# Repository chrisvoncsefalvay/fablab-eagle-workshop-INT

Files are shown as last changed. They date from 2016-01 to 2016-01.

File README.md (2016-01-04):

# FabLab EAGLE workshop (INTRODUCTORY)
The official repo for the Munich Fablab EAGLE introductory course 

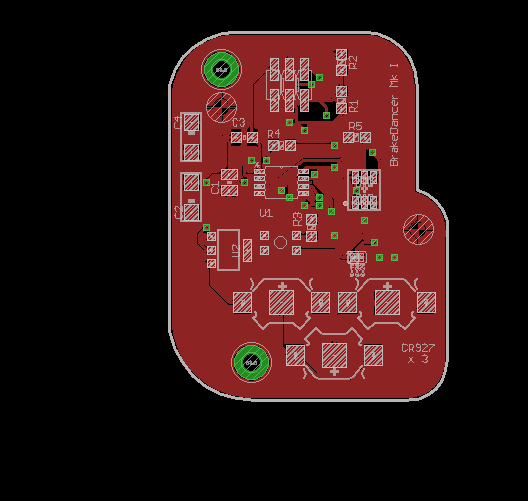
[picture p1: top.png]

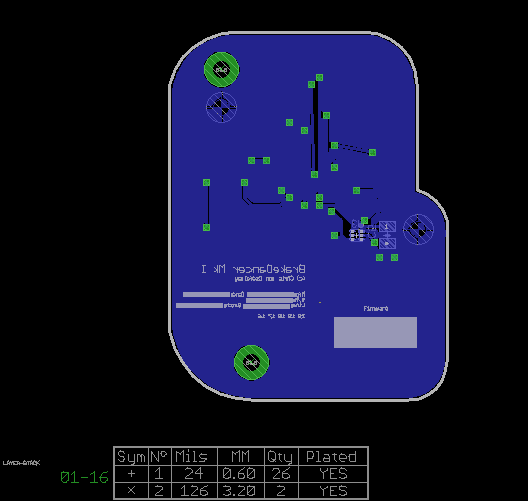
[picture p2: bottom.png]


## The board
The board used to demonstrate EAGLE's functionality is a small ATtiny based brake light tester. The general idea is as follows. Upon resetting the device, an ambient light measurement is taken for five seconds. At the end of the five seconds, you must have attached the device to your light. The device then enters measurement mode. The LED will light up red and turn green if and only if the brake light has lit up. After 60 seconds of no signal, the device will enter sleep. 

### Specs
The device must accommodate the ATtiny, an I2C based light sensor, a battery, a tricolour LED, a power management circuit and all else that's needed for the board's functioning.

The board is driven by three 3V CR927 batteries in series, yielding 9V. This is converted to 5V by the LDO (U2).

Most of the heavy lifting is done by the MCU. The MCU has to be programmable through ICSP headers, though these will not necessarily be mounted in production devices (potentially replaced by a pogo/bed of nails approach).

### Implementation

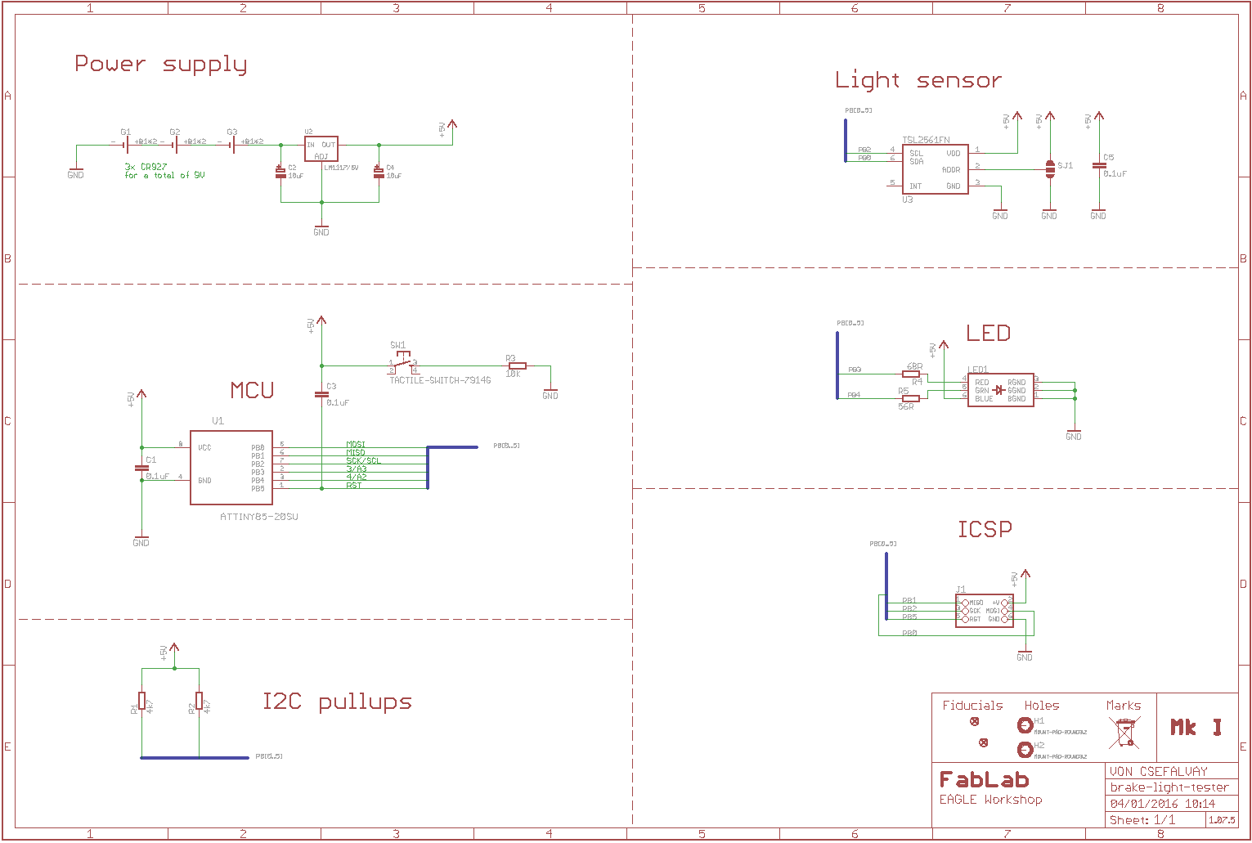
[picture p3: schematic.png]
Schematic


This is a possible implementation, but not the only possible implementation. Be creative, use your mind.

### Board design considerations
The usual considerations apply, but don't forget to
- leave enough space,
- provide fiducials and mount holes,
- use largeish components (1206/1210) and large pads for hand soldering ('W pads') where available,
- stick to two layers, and
- avoid the autorouter.

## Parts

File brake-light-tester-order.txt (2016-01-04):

Order list for /Users/CVoncsefalvay/Developer/fablab-EAGLE-training/brake-light-tester.sch
Exported from EAGLE with DesignLink

Quantity	Value	Package	Order code	Manufacturer	Manuf. Code	Availability	Price (from)	Description
2	0.1uF	C1210	2211074	TDK	CGA5L2C0G1H104J160AA	29910	0.147	TDK - CGA5L2C0G1H104J160AA - CAP, MLCC, C0G/NP0, 100NF, 50V, 1206
2	10uF	EIA6032-28/C-R	197130	AVX	TAJA106K010RNJ	28494	0.0741	AVX - TAJA106K010RNJ - CAP, TANT, 10UF, 10V, CASE A
1	0.1uF	C1206	2211074	TDK	CGA5L2C0G1H104J160AA	29910	0.147	TDK - CGA5L2C0G1H104J160AA - CAP, MLCC, C0G/NP0, 100NF, 50V, 1206
2	FIDUCIALROUND	PASS-ROUND	unknown					
3	10MM_SM_COIN_CELL_CLIP	10MM_SM_COIN_CELL_CLIP	unknown					
2	MOUNT-PAD-ROUND3.2	3,2-PAD	unknown					
1	CON_HEADER_PRG_AVR_ICSP-SMD	M2X3_SMD	unknown					
1		RGBLED_PLCC6	unknown					
2	4k7	R1206	1576638	MULTICOMP	MCHP06W2F4701T5E	43822	0.0145	MULTICOMP - MCHP06W2F4701T5E - RES, THICK FILM, 4K7, 1%, 0.5W, 1206
1	10k	R1206	1469970	VISHAY DRALORIC	CRCW120610K0FKEA	48858	0.0035	VISHAY DRALORIC - CRCW120610K0FKEA - RES, THICK FILM, 10K, 1%, 0.25W, 1206
1	68R	R1206	8067635	YAGEO (PHYCOMP)	RL1206FR-7W0R68L	3000	0.0534	YAGEO (PHYCOMP) - RL1206FR-7W0R68L - RES, THICK FILM, 0R68, 1%, 0.5W, 1206
1	56R	R1206	2057808	PANASONIC ELECTRONIC COMPONENTS	ERJ8GEYJ560V	56569	0.0036	PANASONIC ELECTRONIC COMPONENTS - ERJ8GEYJ560V - RES, THICK FILM, 56R, 5%, 0.25W, 1206
1		SJ_3_PASTE1&2	unknown					
1	TACTILE-SWITCH-7914G	7914G	unknown					
1	ATTINY85-20SU	SOIC127P798X216-8N	1455164	ATMEL	ATTINY85-20SU	4499	0.471	ATMEL - ATTINY85-20SU - MCU, 8BIT, ATTINY, 20MHZ, SOIC-8
1	LM1117/5V	SOT223-R	unknown					
1	TSL2561FN	FN-6	unknown

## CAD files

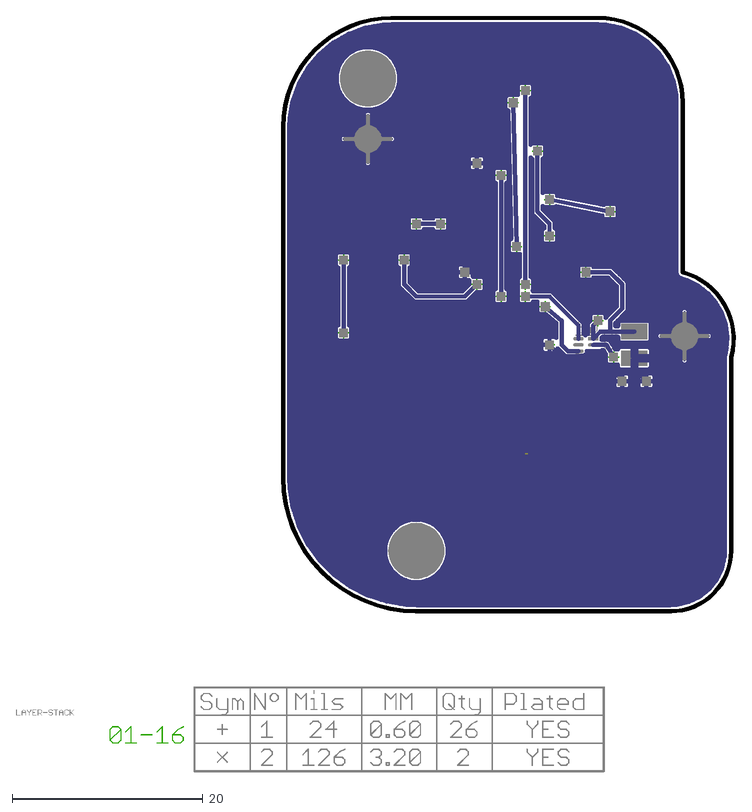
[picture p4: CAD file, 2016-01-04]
brake-light-tester.dxf
75.4 x 79.3

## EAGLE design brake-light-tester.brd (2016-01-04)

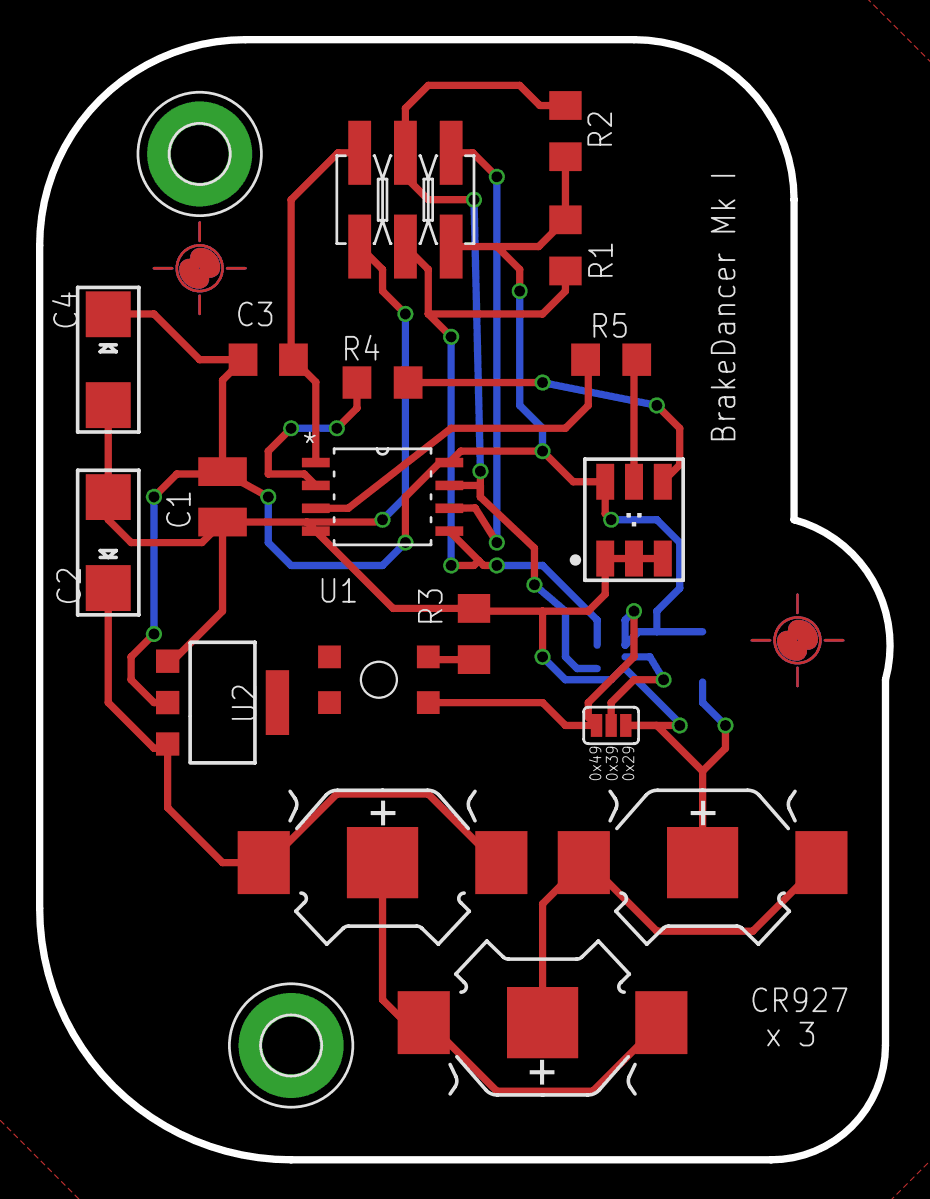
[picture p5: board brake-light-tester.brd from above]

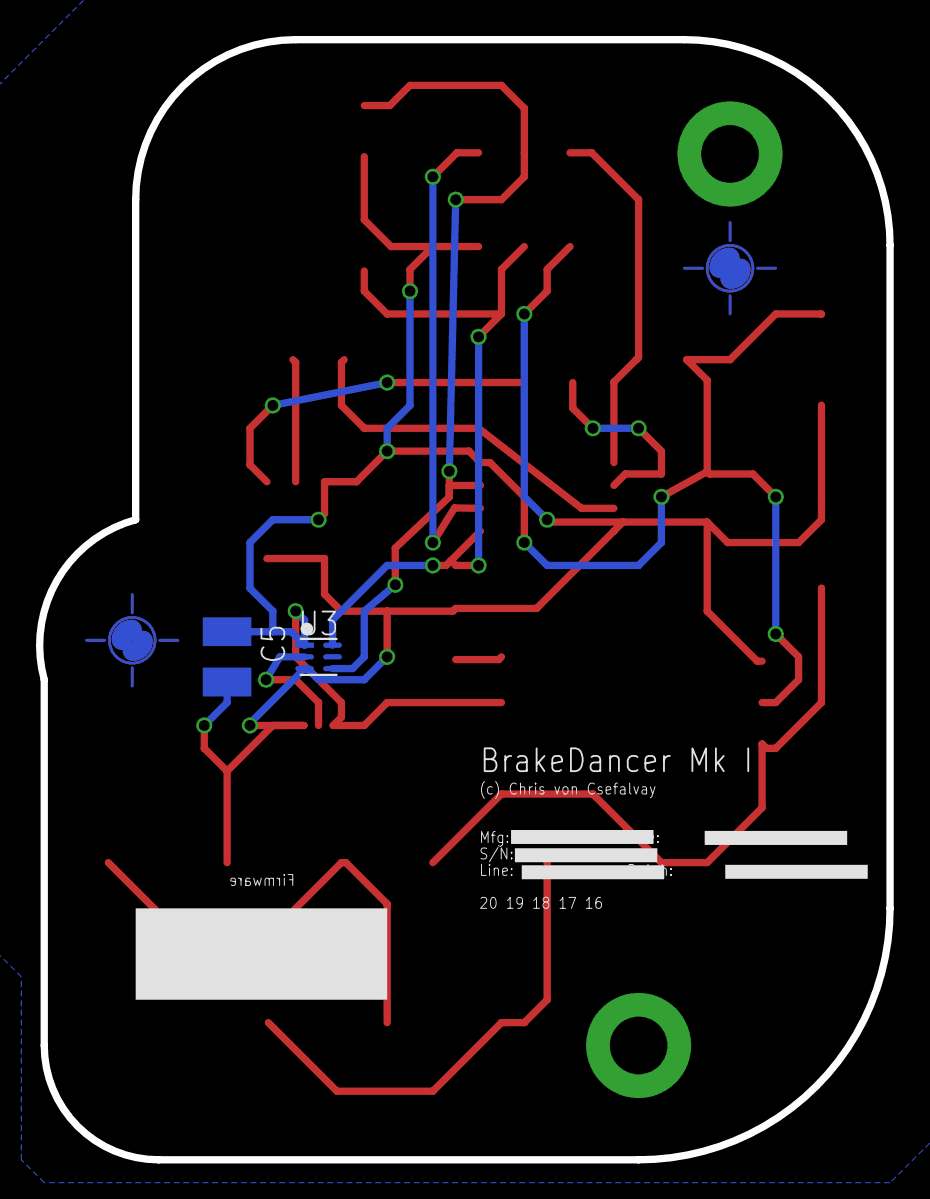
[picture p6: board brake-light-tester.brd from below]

Board: 2 copper layers, 47.2 x 62.2 mm, 25 parts (2 on the bottom side), 15 nets.

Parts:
C1, C5: 0.1uF; C1210
C2, C4: 10uF; EIA6032-28/C-R
C3: 0.1uF; C1206
DRILEGEND: DRILEGEND
FID1, FID2: FIDUCIALROUND; PASS-ROUND
G1, G2, G3: 10MM_SM_COIN_CELL_CLIP
H1, H2: MOUNT-PAD-ROUND3.2; 3,2-PAD
J1: CON_HEADER_PRG_AVR_ICSP-SMD; M2X3_SMD
LED1: RGBLED_PLCC6
R1, R2: 4k7; R1206
R3: 10k; R1206
R4: 68R; R1206
R5: 56R; R1206
SJ1: SJ_3_PASTE1&2
SW1: TACTILE-SWITCH-7914G; 7914G
U1: ATTINY85-20SU; SOIC127P798X216-8N
U2: LM1117/5V; SOT223-R
U3: TSL2561FN; FN-6

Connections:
+5V: C1.1, C3.1, C4.+, C5.1, J1.2, LED1.6, R1.2, R2.2, SJ1.1, SW1.1, U1.8, U2.2, U3.1
GND: C1.2, C2.-, C4.-, C5.2, G1.-, J1.6, LED1.1, LED1.2, LED1.3, R3.2, SJ1.3, U1.4, U2.1, U3.3
unnamed: C2.+, G3.+@1, G3.+@2, U2.3
unnamed: SJ1.2, U3.2
unnamed: LED1.4, R4.1
unnamed: LED1.5, R5.2
unnamed: G1.+@1, G1.+@2, G2.-
unnamed: G2.+@1, G2.+@2, G3.-
unnamed: R3.1, SW1.3
PB0: J1.4, R1.1, U1.5, U3.6
PB1: J1.1, U1.6
PB2: J1.3, R2.1, U1.7, U3.4
PB3: R4.2, U1.2
PB4: R5.1, U1.3
PB5: C3.2, J1.5, U1.1

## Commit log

2016-01-04 Initial commit of completed schematic.
    [brake-light-tester.sch]
2016-01-04 Board generated.
    [brake-light-tester.brd]
2016-01-04 Components laid out but unrouted.
    [brake-light-tester.brd]
2016-01-04 Manually routed PCB, first iteration.
    [brake-light-tester.brd]
2016-01-04 External dimension margins fixed (layer Dimensions).
    [brake-light-tester.brd]
2016-01-04 Top layer GND pour.
    [brake-light-tester.brd]
2016-01-04 Bottom layer GND pour.
    [brake-light-tester.brd]
2016-01-04 Component name silk screen fix.
    [brake-light-tester.brd]
2016-01-04 Final version with silkscreens.
    [brake-light-tester.brd]
2016-01-04 Added drill legend.
    [DRILEGEND.CFG, brake-light-tester.brd]
2016-01-04 Replaced 1210 caps with 1206s as they are much more available.
    [brake-light-tester.brd, brake-light-tester.sch]
2016-01-04 Now includes BOM.
    [brake-light-tester.brd, brake-light-tester.sch]
2016-01-04 T/B images for reference.
    [brake-light-tester.dxf]
2016-01-04 Now includes schematic image.

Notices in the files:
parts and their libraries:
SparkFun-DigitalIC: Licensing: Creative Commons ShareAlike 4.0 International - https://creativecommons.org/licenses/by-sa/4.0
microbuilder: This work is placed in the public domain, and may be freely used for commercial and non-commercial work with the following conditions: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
